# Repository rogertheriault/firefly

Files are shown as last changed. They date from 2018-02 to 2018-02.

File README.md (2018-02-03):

# firefly
An annoying little thing, really

Here's a tiny pcb that you can stash somewhere and annoy people. Where's that chirping coming from?

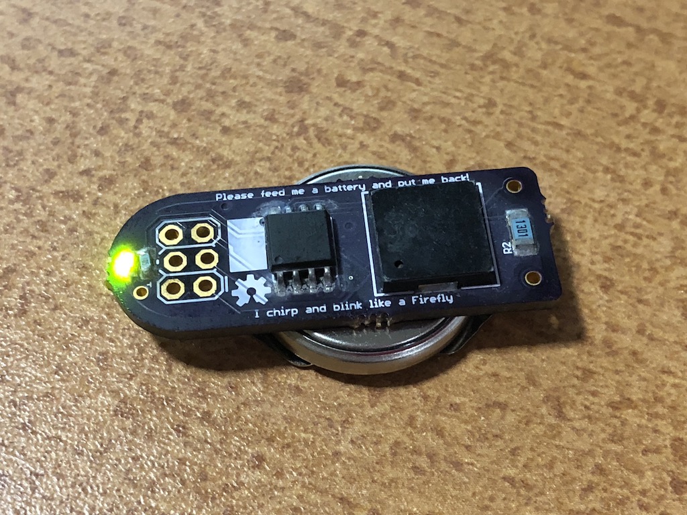
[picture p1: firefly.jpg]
firefly photo assembled Firefly photo


It uses an LED, piezo buzzer, ATTINY13 Atmel microcontroller, a very small amount of Arduino code, and a coin cell battery that should last about a week.

Battery life could be improved, with longer sleep times.

The device has but one function: sleep, then wake up periodically and blink and chirp, then go back to sleep.

You can program the chip using a pogo pin programmer, like [this one from Sparkfun](https://learn.sparkfun.com/tutorials/tiny-avr-programmer-hookup-guide/programming-in-arduino)

### schematic

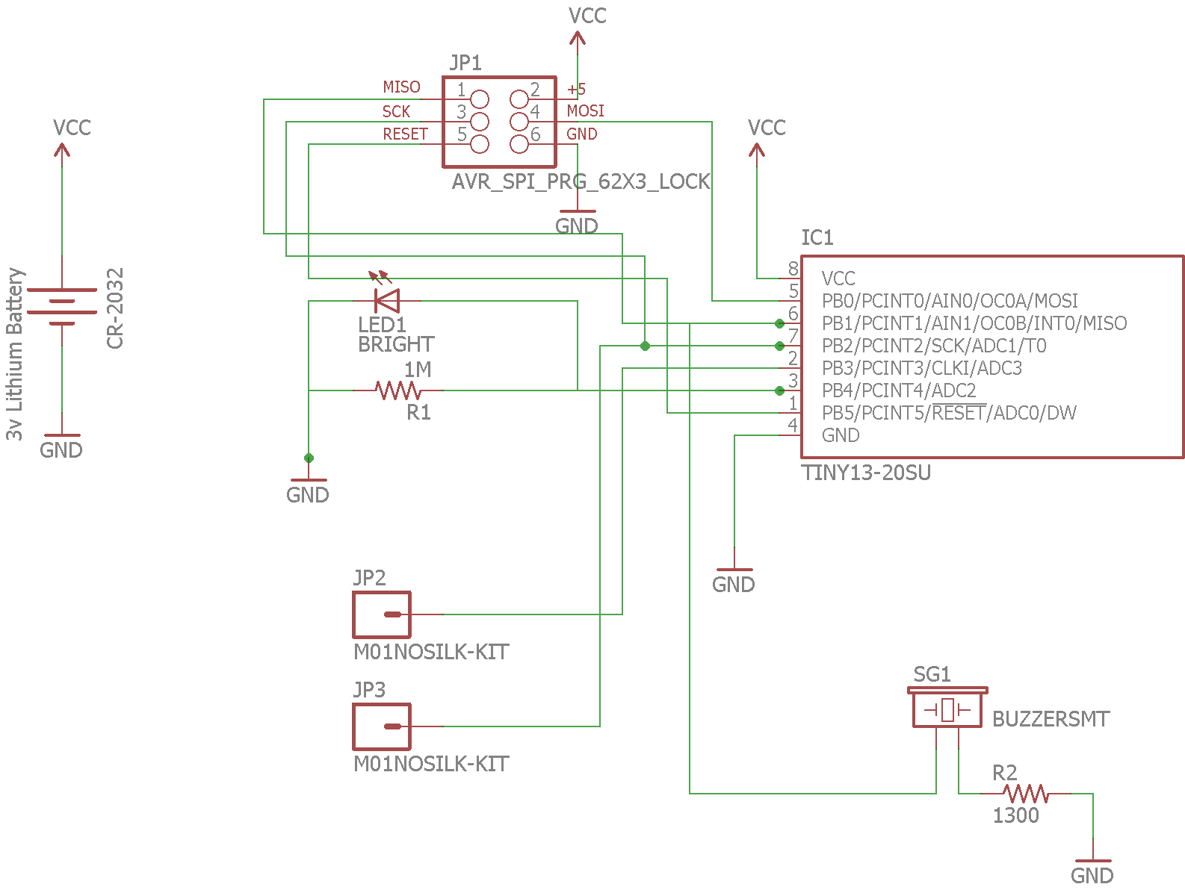
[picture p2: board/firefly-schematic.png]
schematic Schematic Diagram


### parts
Board ID | Part Number | Description | Sources
--- | --- | --- | ---
IC1 | ATTINY13A-SU | SMT Atmel Attiny 13a | Mouser
LED1 | HT-121UYG-4739 | 0603 20ma bright yellow SMT LED | Mouser
SG1 | PKMCS0909E4000-R1 | 9MM square 4KHz piezo buzzer, SMT | Mouser
R1 | 1M   | 0603 1 Meg ohm SMT resistor | Mouser, Newark, Digikey
R2 | 1300 | 1206 1.3K ohm SMT resistor | Mouser, Newark, Digikey
CR-2032 | CR-2032 | 3.3v lithium battery | Mouser, Amazon
Holder |  BAT-HLD-001 | SMT battery holder | Mouser

### PCB

Eagle CAD files are in /board in case you want to iterate

You can also [order these from OshPark](https://oshpark.com/shared_projects/t0UHeqNX)

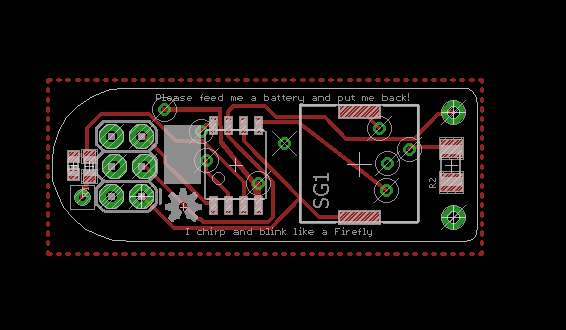
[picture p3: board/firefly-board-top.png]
top layer Board Top

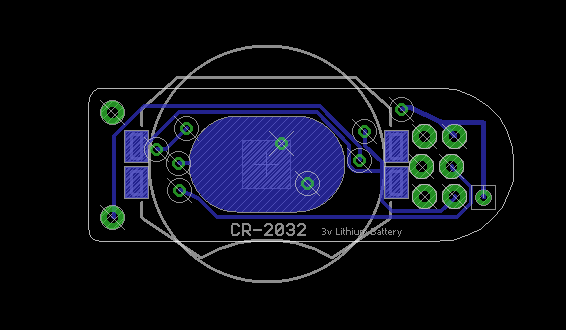
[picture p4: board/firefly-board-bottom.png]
bottom layer Board Bottom


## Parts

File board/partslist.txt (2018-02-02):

Parts

ID       MFR Part

CR-2032  3.3v Lithium Battery  
Holder   BAT-HLD-001 (Mouser stocks)
IC1      ATTINY13A-SU          SMT  Atmel Attiny 13
LED1     HT-121UYG-4739        0603 20ma bright yellow LED
R1       1M                    0603
R2       1300                  1206
SG1      PKMCS0909E4000-R1     9MM square 4KHz Piezo buzzer

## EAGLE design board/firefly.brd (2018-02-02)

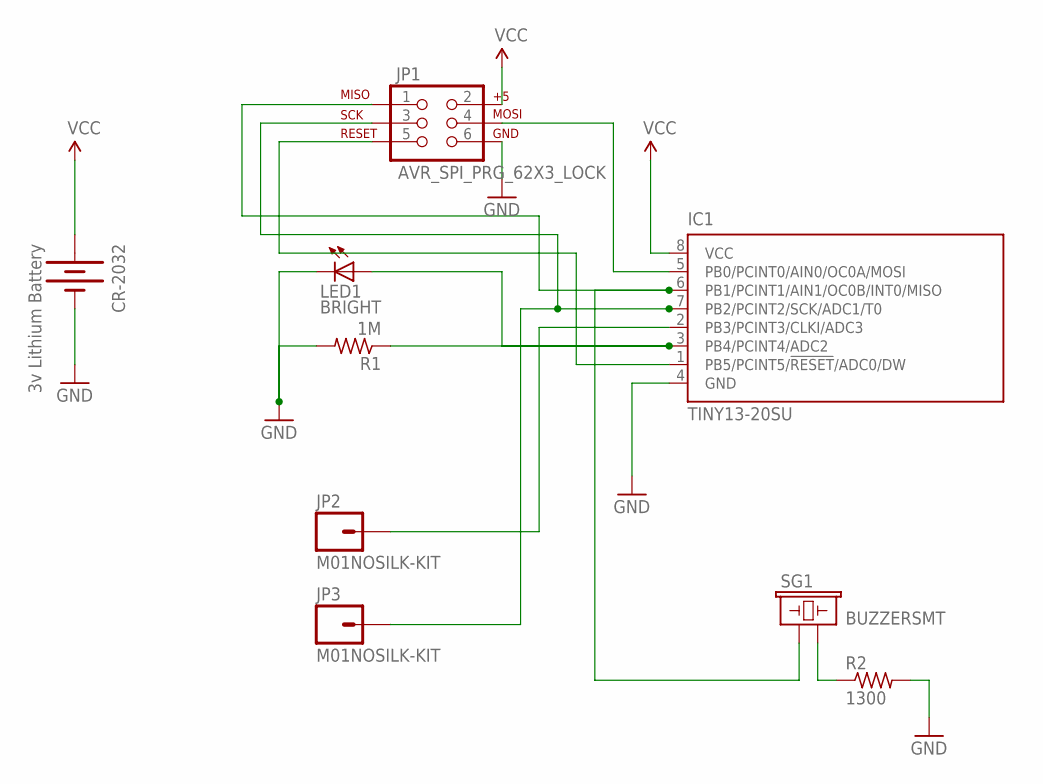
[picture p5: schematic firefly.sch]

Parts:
CR-2032: 3v Lithium Battery; BATTCON_20MM_4LEGS
IC1: TINY13-20SU; 8S2
JP1: AVR_SPI_PRG_62X3_LOCK; 2X3_LOCK
JP2, JP3: M01NOSILK-KIT; 1X01NS-KIT
LED1: BRIGHT; CHIP-LED0603
R1: 1M; R0603
R2: 1300; R1206
SG1: BUZZERSMT; BUZZER-9MM

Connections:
GND: CR-2032.2 (-), IC1.4 (GND), JP1.6, LED1.C, R1.2, R2.2
unnamed: IC1.3 (PB4/PCINT4/ADC2), LED1.A, R1.1
unnamed: IC1.1 (PB5/PCINT5/!RESET!/ADC0/DW), JP1.5
unnamed: IC1.7 (PB2/PCINT2/SCK/ADC1/T0), JP1.3, JP3.1
unnamed: IC1.6 (PB1/PCINT1/AIN1/OC0B/INT0/MISO), JP1.1, SG1.1
unnamed: IC1.5 (PB0/PCINT0/AIN0/OC0A/MOSI), JP1.4
unnamed: IC1.2 (PB3/PCINT3/CLKI/ADC3), JP2.1
unnamed: R2.1, SG1.2
VCC: CR-2032.1 (+), IC1.8 (VCC), JP1.2

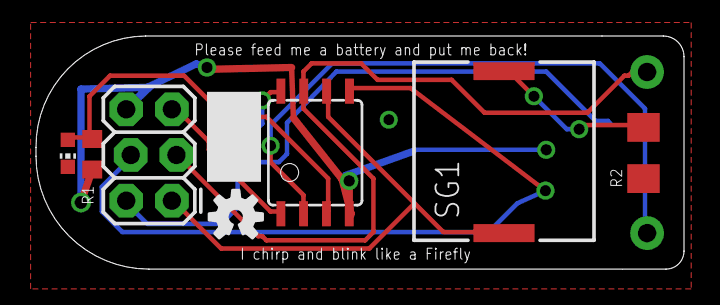
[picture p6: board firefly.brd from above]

Board: 2 copper layers, 36.0 x 12.9 mm, 10 parts (1 on the bottom side), 9 nets.

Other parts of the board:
U$1: OSHW-LOGO-S

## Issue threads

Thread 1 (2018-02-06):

Resistor in parallel?

electrodonkey, 2018-02-06:
I don't think i get the reason for the resistor in parallel with the LED. Is it the current limiting resistor?

rogertheriault, 2018-02-06:
Unimplemented feature - you can use it to measure light. If not planning to do that (you'd need some new code) you can omit it.

Here's the background and inspiration for the board. I just never had time to work on that part.

https://hackaday.com/2013/04/19/asynchronous-fireflies-use-few-parts/

Also the two holes at the opposite end are just there for accessories in case you want to solder on a few antennae :-)

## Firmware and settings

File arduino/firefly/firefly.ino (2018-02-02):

/**
 * firefly
 * 
 * ATTINY13 code for a firefly
 * 
 * Inspired by & based on https://www.seanet.com/~karllunt/fireflyLED.html
 * 
 * 
 */
 
#include <avr/interrupt.h>
#include <avr/sleep.h>
 
#define LED 4 //3
#define PIEZO 1 //0
#define CLOCK_ADJ 5
#define PIEZO_INTERVAL 165 // us
#define PIEZO_COUNT 50 // cycles
#define LIGHT_TIME 250 // ms
#define LIGHT_BETWEEN 100 // ms
#define DARK_MAXTIME 9 // seconds
#define DARK_MINTIME 3 // seconds


void setup() {                

  pinMode(LED, OUTPUT);
  pinMode(PIEZO, OUTPUT);

}


void loop() {
  cricket();
}

ISR( WDT_vect ) {
  // wake the heck up
}

void cricket() {
   
  // double-blink
  chirpled();
  delay( LIGHT_BETWEEN * CLOCK_ADJ );
  chirpled();
  
  // now go to "sleep"
  sleepBetweenChirps();

}

void chirpled() {
  digitalWrite( LED, HIGH );
  for ( int i = 0; i < PIEZO_COUNT; i++ ) {
    digitalWrite( PIEZO, HIGH ); 
    delayMicroseconds( PIEZO_INTERVAL * CLOCK_ADJ ); 
    digitalWrite( PIEZO, LOW ); 
    delayMicroseconds( PIEZO_INTERVAL * CLOCK_ADJ );
  }
  delay( LIGHT_TIME * CLOCK_ADJ );
  digitalWrite( LED, LOW );

}

void sleepBetweenChirps() {

  // add this if you want to use light detection to adjust the sleep time
  //delay( 1000 * DARK_MAXTIME * CLOCK_ADJ );
    
  // prescale timer to 8s
  WDTCR |= ( 1 << WDP3 ) | ( 1 << WDP0 );
    
  // enable watchdog timer interrupts
  WDTCR |= ( 1 << WDTIE );
    

    
  // go to sleep
  set_sleep_mode( SLEEP_MODE_PWR_DOWN );
  
  //sleep_bod_disable();
  // enable global interrupts
  sei();
  sleep_mode();
  sleep_disable();
  
  
}

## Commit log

2018-02-02 Eagle Cad board files and arduino code
    [firefly.brd, firefly.sch]
2018-02-02 flipped bottom board face
2018-02-03 Added parts list and OshPark link to order boards

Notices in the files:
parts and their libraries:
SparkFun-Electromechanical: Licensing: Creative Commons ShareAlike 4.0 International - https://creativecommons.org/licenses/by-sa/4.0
